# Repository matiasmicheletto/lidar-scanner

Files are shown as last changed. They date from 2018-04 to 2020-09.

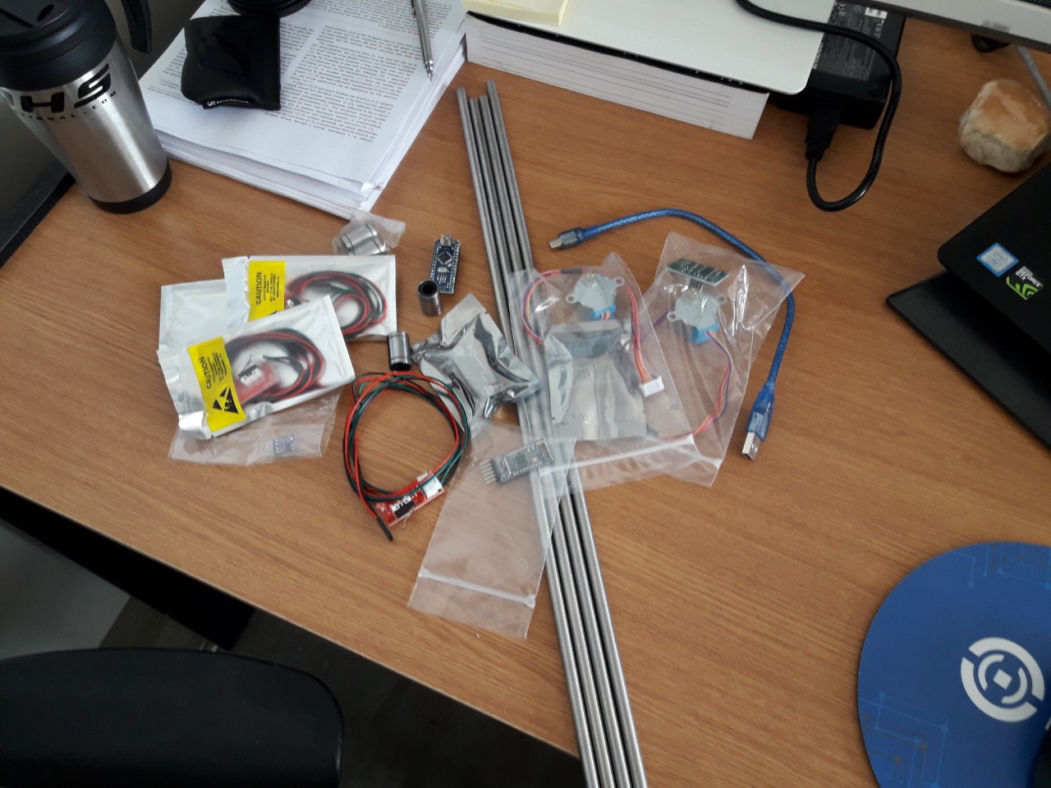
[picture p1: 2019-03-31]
Img/Materiales.jpeg

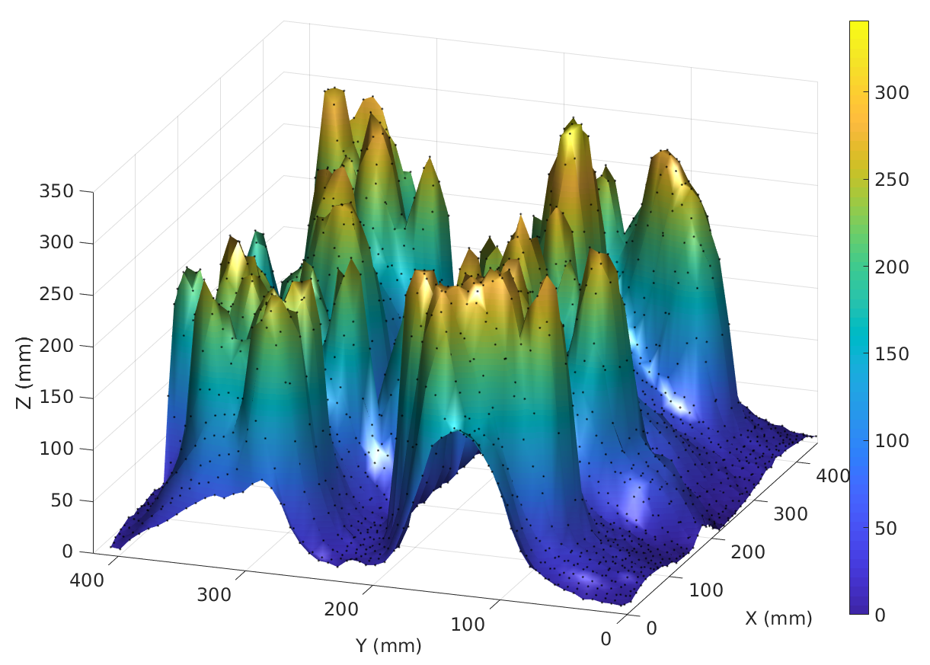
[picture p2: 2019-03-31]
Img/Modelo.png

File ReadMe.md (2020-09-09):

# Escáner Lidar para Análisis Tridimensional de Cobertura Vegetal de Suelos

Demo funcionando (https://www.youtube.com/watch?v=0Rp_0J8g25A)

## Resumen
http://47jaiio.sadio.org.ar/sites/default/files/CAI-10.pdf
"La erosión hídrica y eólica del suelo sobre el que se realizan actividades de producción agrícola implica la pérdida de nutrientes y microorganismos importantes. La presencia de rastrojos o cultivos de cobertura reduce en gran medida la erosión eólica al frenar el viento sobre la superficie, reduce la erosión hídrica al impedir el escurrimiento de agua, evita la pérdida de humedad por evaporación al estar el suelo protegido de la radiación solar, y también se evita fenómenos como el 'planchado' o 'sellado' del suelo que impide la emergencia de los cultivos sembrados luego de lluvias intensas. La cobertura vegetal debe contar con ciertas características para optimizar la calidad del suelo, y entre éstas se puede mencionar su altura y densidad volumétrica por lo que contar con un instrumento para la medición de éstas variables resulta de interés. Se presenta en este trabajo un prototipo que permite escanear la superficie del suelo midiendo la altura de la cobertura vegetal mediante un sensor de distancia accionado mediante un mecanismo CNC. Se detalla el funcionamiento tanto del sistema mecánico como electrónico y del software implementado como así también los resultados de las pruebas experimentales."

Ing. Electr. Matías Micheletto | Dep. de Ing. Eléctrica y Computadoras, IIIE Universidad Nacional del Sur - CONICET

### Contacto
LSD | Laboratorio de Sistemas Digitales  
DIEC | Departamento de Ingeniería Eléctrica y Computadoras  
UNS | Universidad Nacional del Sur  
San Andrés 800, CP8000 Bahía Blanca  
Buenos Aires, Argentina  
Teléfono: +54 291 4595153/4  
Website: http://www.diec.uns.edu.ar/rts

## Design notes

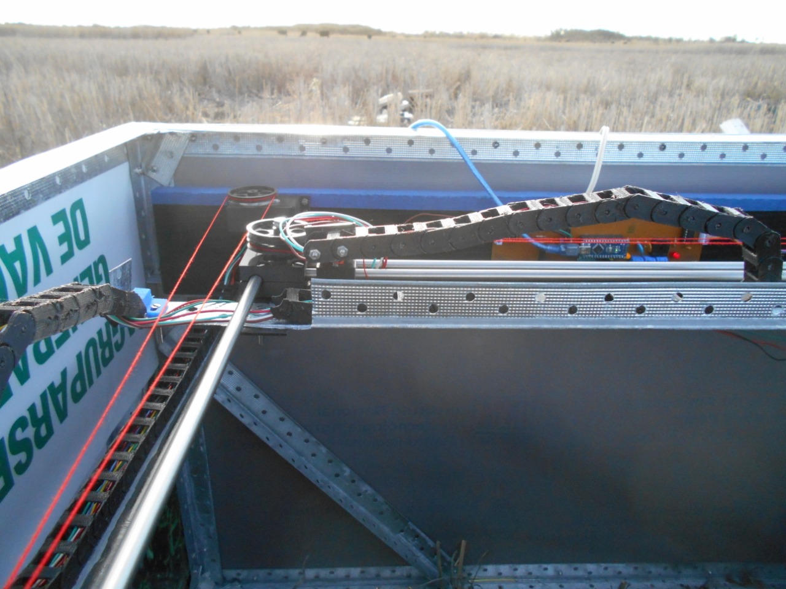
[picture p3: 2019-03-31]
Img/Campo3.jpeg

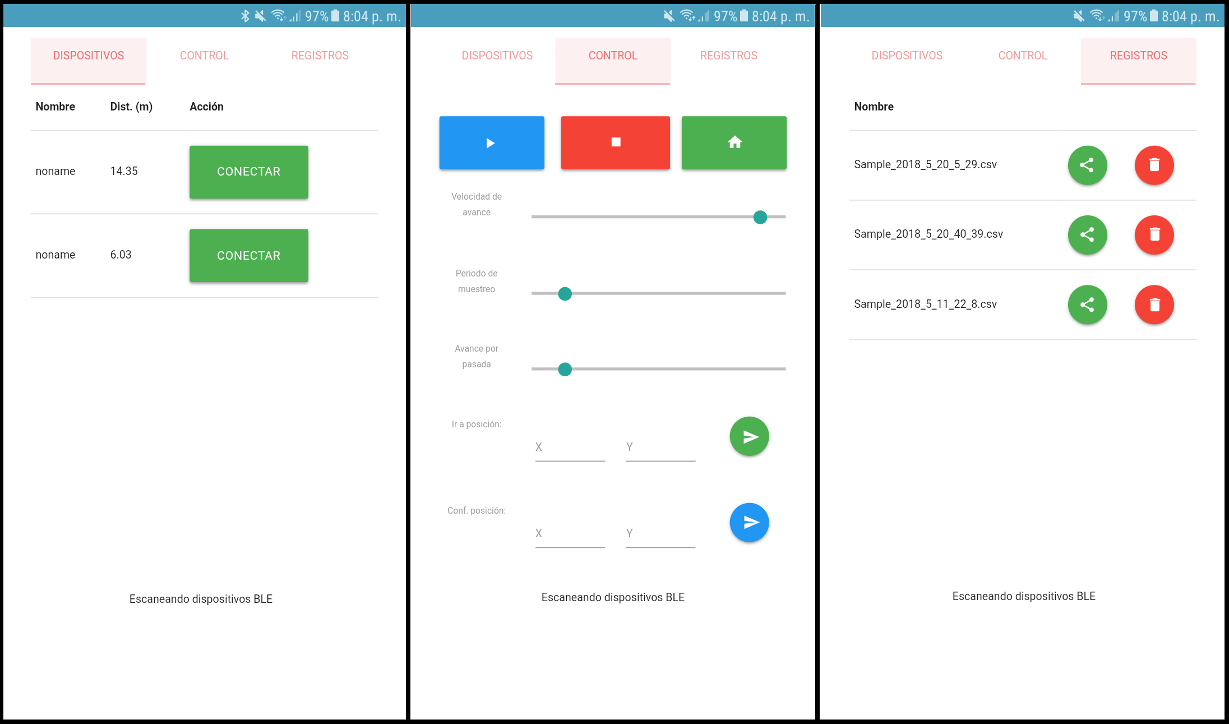
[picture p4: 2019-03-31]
Img/App.png

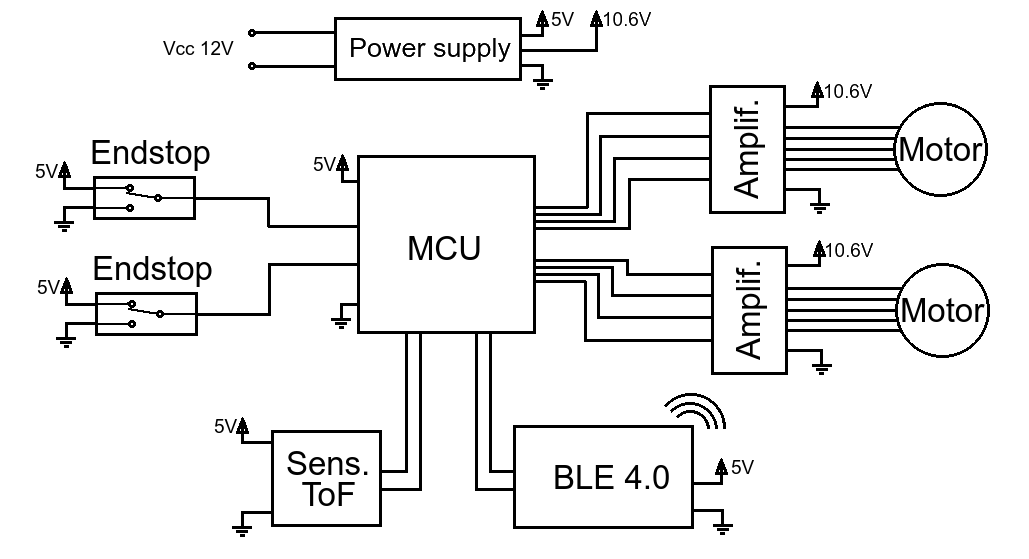
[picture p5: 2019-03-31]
Img/EsquemaGralElectrico.png

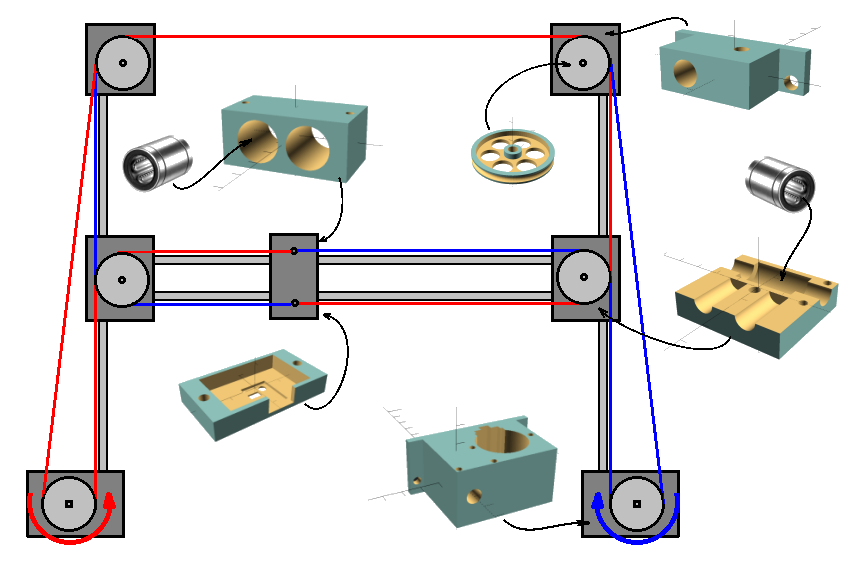
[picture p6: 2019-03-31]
Img/Mecanica13.png

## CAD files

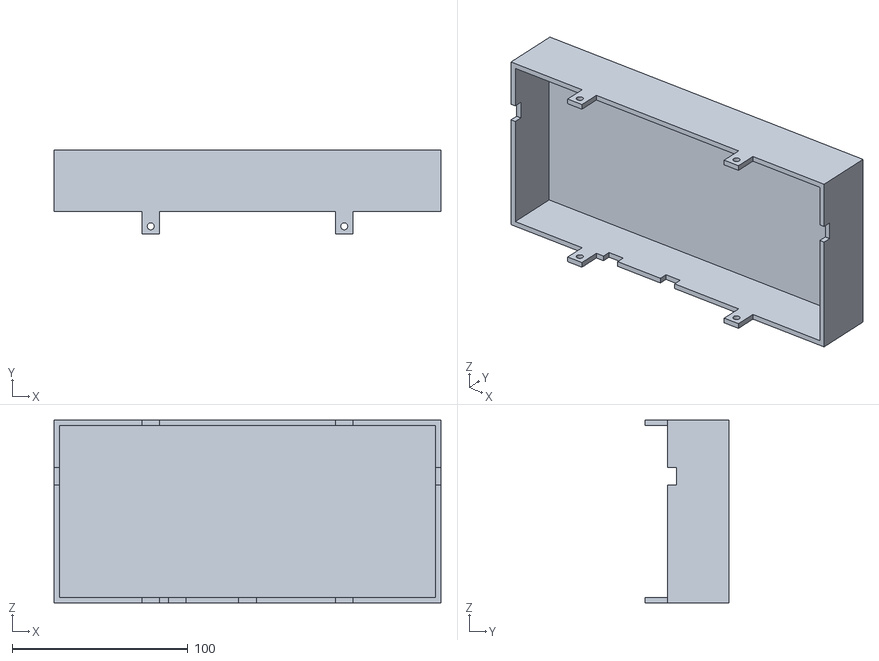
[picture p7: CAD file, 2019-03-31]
Partes/Gabinete.stl
220.0 x 48.0 x 104.0

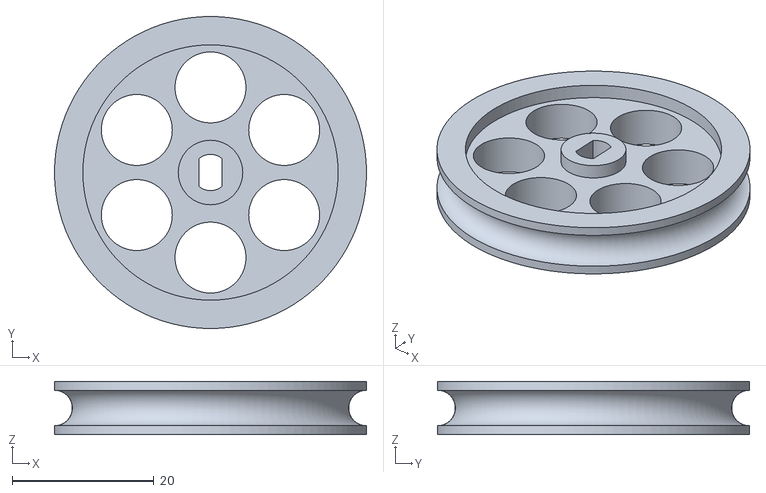
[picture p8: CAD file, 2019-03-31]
Partes/PoleaPistaAlta.stl
44.0 x 44.0 x 7.50

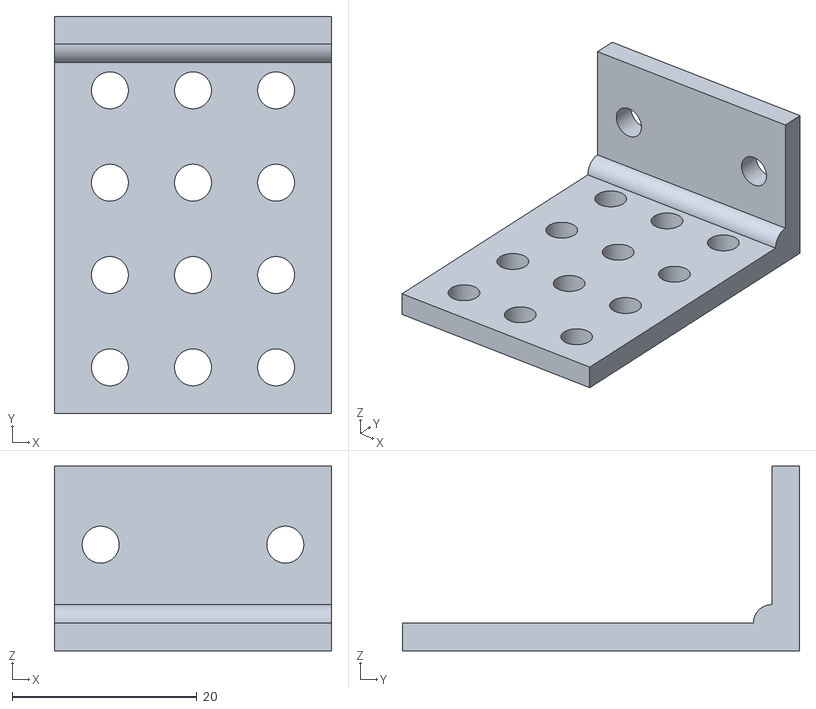
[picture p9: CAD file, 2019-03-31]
Partes/AnguloSoporteEstruc.stl
30.0 x 43.0 x 20.0

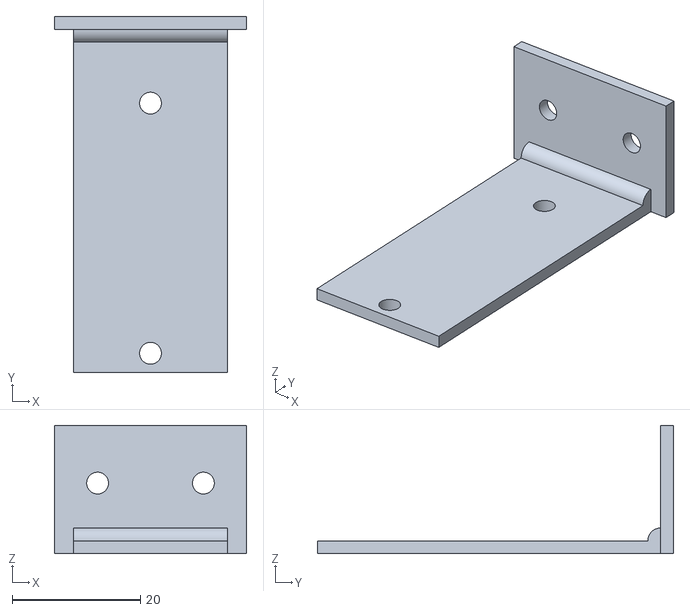
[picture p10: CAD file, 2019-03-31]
Partes/SoporteCadena.stl
30.0 x 55.5 x 20.0

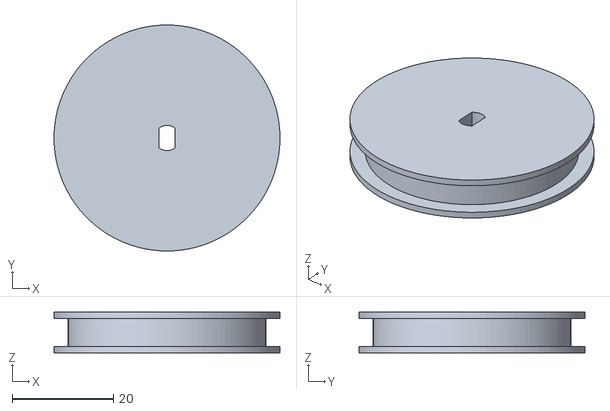
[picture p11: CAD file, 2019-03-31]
Partes/PoleaPistaRecta.stl
44.6 x 44.6 x 8.00

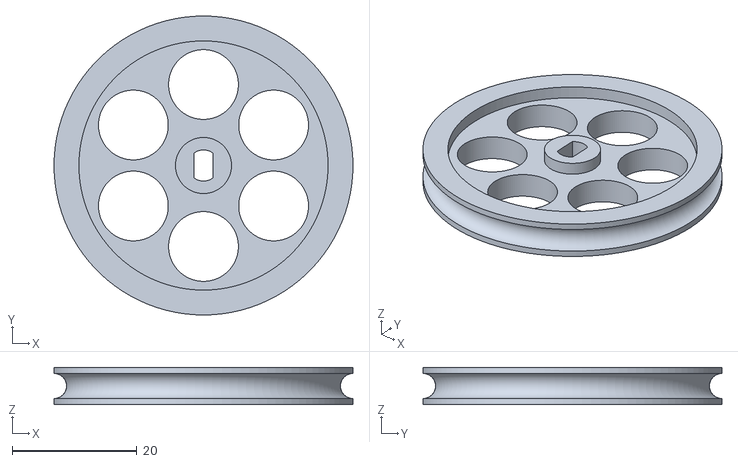
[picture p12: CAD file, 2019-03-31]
Partes/PoleaMotor.stl
48.0 x 48.0 x 6.00

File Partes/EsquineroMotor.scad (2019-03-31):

/*
    Scanner para análisis tridimensional de cobertura vegetal del suelo
    
    Descripción de la pieza: Soporte para las guias de desplazamiento Y y para los motores paso a paso. Posee espacio para ajustar los interruptores de fin de carrera.
    Cantidad requerida: 2.

    Autor: Matias J. Micheletto    
    Noviembre 2017
    Directores: Rodrigo Santos - Juan Galantini
    Laboratorio de Sistemas Digitales
    Universidad Nacional del Sur - Departamento de Ingeniería Eléctrica y Computadoras    
*/

$fn = 100;  // Resolucion del modelo

// Dimensiones exteriores del montaje
W = 57;     // Ancho (en direccion X)
L = 40;     // Largo (en direccion Y)
d = -19;      // Desplazamiento lateral

Ry = 4.1;   // Radio del orificio para eje y

ls = 4;     // Espesor de pared posterior
ds = 8;     // Ancho hacia los costados
Rs = 2.25;  // Radio de los agujeros para soportes

// Dimensiones del motor
dm = 39-12.25; // Separacion entre el eje Y y el eje del motor
Rm = 14+0.1; // Radio del motor
r2 = 1.7; // Radio de los agujeros para tornillos
d2 = 35; // Separacion entre los tornillos

// Espacio para soporte de cables
wc1 = 3+0.2; // Largo parte ancha
lc1 = 17+0.2; // Ancho parte ancha
xc1 = -dm+sqrt(Rm*Rm-lc1*lc1/4)+wc1/2; // Posicion del centro del cuadrado
wc2 = 5+0.2; // Largo parte angosta
lc2 = 14.5+0.2; // Ancho parte angosta
xc2 = -dm+sqrt(Rm*Rm-lc2*lc2/4)+wc2/2; // Posicion del centro del cuadrado
wc3 = 7; // Largo parte angosta
lc3 = 6; // Ancho parte angosta
xc3 = -dm+sqrt(Rm*Rm-lc3*lc3/4)+wc3/2; // Posicion del centro del cuadrado

// Ajuste del endstop
d3 = 19; // Separacion entre los tornillos

module pieza(H){ // Se pasa como argumento la altura de la pieza para dibujar una de las mitades mas alta
    difference(){ 
        // Envolvente        
        union(){
            translate([d,0,0])
                cube([W,L,H],center = true);
            translate([d,L/2-ls/2+ls,0])
                cube([W+2*ds,ls,H], center = true);
        }
            
        // Espacio para la guia de acero
        translate([0,-L/2+21/2,0])
        rotate([90,0,0])              
            cylinder(r = Ry, h = 21, center = true);                
           
        // Hueco para el motor
        translate([-dm,0,0])
            cylinder(r = Rm, h = H, center = true);
           
        // Orificios para los tornillos del motor        
        translate([-dm-d2/2,0,0])
            cylinder(r = r2, h = H, center = true);    
        translate([-dm+d2/2,0,0])
            cylinder(r = r2, h = H, center = true);
        
        // Espacio para los conectores del motor
        translate([-dm,xc1+dm,0])
            cube([lc1,wc1,H], center = true);
        translate([-dm,xc2+dm,0])
            cube([lc2,wc2,H], center = true);
        translate([-dm,xc3+dm,0])
            cube([lc3,wc3,H], center = true);    
        
        // Agujeros de soporte
        translate([W/2+ds/2+d,L/2+ls/2,-H/4])
        rotate([90,0,0])
            cylinder(r = Rs, h = ls, center = true);
        translate([-W/2-ds/2+d,L/2+ls/2,-H/4])
        rotate([90,0,0])
            cylinder(r = Rs, h = ls, center = true);  
        /*translate([W/2+ds/2+d,L/2+ls/2,H/4])
        rotate([90,0,0])
            cylinder(r = Rs, h = ls, center = true);
        translate([-W/2-ds/2+d,L/2+ls/2,H/4])
        rotate([90,0,0])
            cylinder(r = Rs, h = ls, center = true);*/
        
        
        // Agujeros para tornillos del endstop    
        translate([W/2-r2+d-0.5,-L/2+r2+0.5,0])   
            cylinder(r = r2, h = H, center = true);
        translate([W/2-r2+d-0.5-d3,-L/2+r2+0.5,0])   
            cylinder(r = r2, h = H, center = true);                
        
        // Dibujar solo la mitad de abajo
        translate([d,ls/2,H/4])
            cube([W+2*ds,L+ls,H/2], center = true);              
    }
}

pieza(32);
mirror([0,1,0]) // Reflejar respecto del plano XZ
translate([0,L+2,-6])
    pieza(20); // Uno de los motores debe ir mas alto que el otro

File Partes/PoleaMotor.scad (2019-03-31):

/*
    Scanner para análisis tridimensional de cobertura vegetal del suelo
    
    Descripción de la pieza: Polea de 40mm de diametro para motor paso a paso BYj48.
    Cantidad requerida: 2.

    Autor: Matias J. Micheletto    
    Noviembre 2017
    Directores: Rodrigo Santos - Juan Galantini
    Laboratorio de Sistemas Digitales
    Universidad Nacional del Sur - Departamento de Ingeniería Eléctrica y Computadoras    
*/

$fn = 100;      // Resolucion del modelo

H = 6;        // Altura
Rp = 2;       // Radio de la pista (menor que H/2)
R = 22+Rp;    // Radio exterior (original 19.5+Rp)

Ra = 2.50;      // Radio eje
Rb = 1.55;      // Achatamiento

// Orificios
Nh = 6;         // Cantidad
Rh = 5.6;         // Radio (original 5)
Dh = R/2+1;     // Separacion desde el centro

// Ahuecamiento
Di = 2;         // Borde interior
De = 4;         // Borde exterior
e = 2;          // Profundidad

    
    

difference(){
    cylinder(r = R, h = H); // Envolvente

    intersection(){
        cylinder(r = Ra, h = H); // Eje
        translate([0,0,H/2])
            cube([Rb*2,Ra*2,H], center = true);
    }

    // Pista para la cuerda convexa
    rotate_extrude(convexity = 10)
    translate([R, H/2, 0])
        circle(r = Rp);  
    
    // Pista para cuerda recta
    //translate([0,0,(H-Rp*2)/2])
    //difference(){
    //    cylinder(r = R, h = Rp*2);
    //    cylinder(r = R-Rp, h = Rp*2);
    //}
    

    // Orificios
    for(angle = [0 : 360/Nh : 360])
        translate([Dh*sin(angle),Dh*cos(angle),0])
            cylinder(r = Rh, h = H); 

    // Ahuecamiento superior
    translate([0,0,H-e])
        difference(){
            cylinder(r = R-De, h = e);
            cylinder(r = Ra+Di, h = e);
        }
}

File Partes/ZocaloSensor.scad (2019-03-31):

/*
    Scanner para análisis tridimensional de cobertura vegetal del suelo
    
    Descripción de la pieza: Zócalo para sensor laser VL53L0X. Va atornillado a la base del carro móvil que se desplaza sobre el eje X.
    Cantidad requerida: 1.

    Autor: Matias J. Micheletto    
    Noviembre 2017
    Directores: Rodrigo Santos - Juan Galantini
    Laboratorio de Sistemas Digitales
    Universidad Nacional del Sur - Departamento de Ingeniería Eléctrica y Computadoras    
*/

$fn = 100; // Resolucion del modelo

// Dimensiones exteriores del montaje
W = 24; // Ancho (en direccion X)
L = 45; // Largo (en direccion Y)
H = 7.5;  // Altura (en direccion Z)
e = 1.6;  // Espesor fondo y paredes

// Dimensiones del sensor
Ws = 2.4+0.2; // Ancho (X)
Ls = 4.4+0.2; // Alto (Y)

// Dimensiones y posicion de la plaqueta
Wp = 13.3+0.2; // Ancho (X)
Lp = 10.4+0.2; // Largo (Y)
ep = 1; // Espesor del hundimiento
xp = -2.2;
yp = -2.3;

// Dimensiones y posicion del tornillo de la plaqueta
Rs = 1.3+0.2; // Radio del orificio para el tornillo de la plaqueta
xs = 1.9;
ys = -4.7;

// Tornillos de ajuste
Rp = 1.8; // Radio de los orificios para tornillos
s = 1.5; // Separacion entre el orificio y el borde de la pieza



difference(){
    // Envolvente
    cube([W,L,H], center = true);
    
    // Interior
    translate([0,0,e/2])
        cube([W-2*e,L-4*s-4*Rp,H-e], center = true);
    
    // Agujeros para tornillos
    translate([0,L/2-Rp-s,0])
        cylinder(r = Rp, h = H, center = true);
    translate([0,-L/2+Rp+s,0])
        cylinder(r = Rp, h = H, center = true);
    
    // Orificio para sensor (centrado)
    translate([0,0,-H/2+e/2])
        cube([Ws,Ls,e], center = true);
    
    // Orificio para tornillo de la plaqueta
    translate([xs,ys,-H/2+e/2])
        cylinder(r = Rs, h = e, center = true);
    
    // Hueco para plaqueta    
    translate([xp,yp,-H/2+e-ep/2])
        cube([Wp,Lp,ep], center = true);
        
    // Agujero para sacar los cables
    translate([-W/2+e/2,yp,e/2])
        cube([e,Lp,H-e], center = true);
}

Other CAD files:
Partes/AnguloSoporteEstruc.scad
Partes/CadenaArrastre.scad
Partes/Carro.scad
Partes/Esquinero.scad
Partes/Gabinete.scad
Partes/MontajeCarro.scad
Partes/Polea.scad
Partes/SoporteCadena.scad
Partes/TopeEndstop.scad

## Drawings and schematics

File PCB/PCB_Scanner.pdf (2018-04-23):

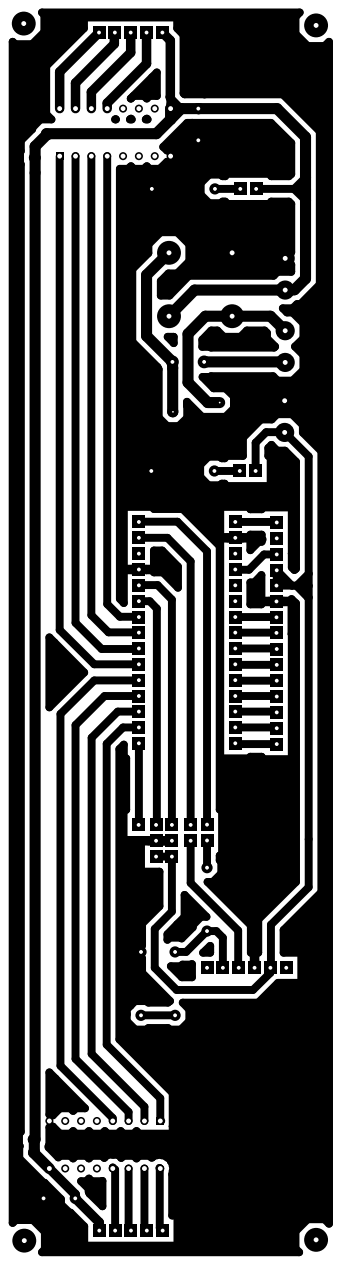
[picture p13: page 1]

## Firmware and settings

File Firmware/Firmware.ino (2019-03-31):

/**
  ******************************************************************************
  *  Name        : Firmware.ino
  *  Author      : Matias Micheletto
  *  Version     : 1.0
  *  Copyright   : GPLv3
  *  Description : Firmware de scanner lidar de cobertura vegetal
  ******************************************************************************
  *
  *  Copyright (c) 2018
  *  Matias Micheletto <matias.micheletto@uns.edu.ar>
  *  Departamento de Ingeniería Eléctrica - Universidad Nacional del Sur
  *  Laboratorio de Sistemas Digitales
  *
  *
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
  ******************************************************************************
  */

#include <Wire.h>
#include "BYJ48.h"
#include "VL53L0X.h"

#define ES_PIN1 2 // Pin para endstop de direccion X
#define ES_PIN2 3 // Pin para endstop de direccion Y
//#define OK_PIN A0 // Pin para led de encendido
//#define ERR_PIN A1 // Pin para led de errores
//#define MAXPOSX 14600 // Maxima posicion a desplazarse en X (446mm)
//#define MAXPOSY 13300 // Maxima posicion a desplazarse en Y (410mm)
#define MAXPOSX 13000 // Maxima posicion a desplazarse en X (446mm)
#define MAXPOSY 11700 // Maxima posicion a desplazarse en Y (410mm)

// Sensor laser
VL53L0X sensor;

// Motores
BYJ48 motor1(4,5,6,7); // Motor izq.
BYJ48 motor2(8,9,10,11); // Motor der.

boolean scanning = false; // Habilita o deshabilita el muestreo del sensor
boolean moving = false; // Habilita las instrucciones de la ISR del TIMER2 (Para accionar motores)
int pos[2] = {MAXPOSX,MAXPOSY}; // Posicion inicial del sensor (se asume)
int sp[2] = {0,0}; // Setpoint (inicialmente debe ester en 0,0)
int hSweep = 300; // Pasos de separacion entre cada pasada horizontal (divisor de MAXPOSY)
byte motorSpeed = 12; // Valor defeecto del registro de comparacion para ISR valor = 16MHz/1024/freq 
int samplePeriod = 250; // Periodo de muestreo del sensor
unsigned long previousMillis = 0;

void setup(){

  // Inicializar sensor laser
  Wire.begin();
  sensor.init();
  sensor.setTimeout(500); // Maximo periodo de espera
  sensor.setMeasurementTimingBudget(200000); // Modo high accuracy

  pinMode(ES_PIN1,INPUT);
  pinMode(ES_PIN2,INPUT);
  //pinMode(OK_PIN,OUTPUT);
  //pinMode(ERR_PIN,OUTPUT);

  Serial.begin(9600); // Inicializar interface uart (para bluetooth o usb)
  delay(500);

  goHome(); // Se ingresa como setpoint el origen (0,0)

  // Para que no se mueva en el inicio. Si se desea volver al home se puede con el comando correspondiente
  pos[0] = 0;
  pos[1] = 0;

  // Configurar registros de interrupcion
  configureSpeed(motorSpeed);

  // Encender led de status
  //digitalWrite(OK_PIN,HIGH);

  
  /*
  // Configuracion del modulo
  delay(1000);
  Serial.println("AT");
  delay(500);
  Serial.println("AT+ROLE0"); // Slave
  delay(500);
  Serial.println("AT+UUID0xFFE0"); // UUID
  delay(500);
  Serial.println("AT+CHAR0xFFE1"); // Characteristic
  delay(500);
  Serial.println("AT+NAMEScanner"); // Name
  delay(500);
  */
}

void es1_activated(){ // Interrupcion por activacion del endstop de direccion X
  pos[0] = 0; // Restablecer posicion horizontal
}

void es2_activated(){ // Interrupcion por activacion del endstop de direccion Y
  pos[1] = 0; // Restablecer posicion vertical
}

ISR(TIMER2_COMPA_vect){ // Interrupcion por timer 2 - Control de motores
  if(moving){ // Para deshabilitar el uso de la cola de setpoint en interrupciones
    if(pos[0] == sp[0] && pos[1] == sp[1]){ // Si se alcanza el setpoint
      if(scanning && pos[0] < MAXPOSX){ // Si hay otro setpoint al que ir
        // Poner siguiente sp
        if(pos[1] == MAXPOSY){          
          sp[0] = pos[0]+hSweep;
          sp[1] = 0;
        }else{
          sp[0] = pos[0]+hSweep;
          sp[1] = MAXPOSY;
        }
      }else{ // Si no hay mas setpoints, apagar steppers y salir
        motor1.disable();
        motor2.disable();
	      moving = false; // Deshabilitar el cuerpo de la ISR para no usar cola
        scanning = false; // Deshabilitar el envio de datos
        return;
      }
    }
    if(pos[0] < sp[0]){ // Mover izquierda
      motor1.stepCCW();
      motor2.stepCCW();
      pos[0]++;
      return;
    }
    if(pos[0] > sp[0]){ // Mover derecha
      motor1.stepCW();
      motor2.stepCW();
      pos[0]--;
      return;
    }
    if(pos[1] < sp[1]){ // Mover arriba
      motor1.stepCW();
      motor2.stepCCW();
      pos[1]++;
      return;
    }
    if(pos[1] > sp[1]){ // Mover abajo
      motor1.stepCCW();
      motor2.stepCW();
      pos[1]--;
      return;
    }
  }
}

void startScanning(){ // Crear cola de posiciones para barrido izq-der y abajo-arriba iniciando desde la pos. vert. actual
  scanning = false; // Deberia estar en false antes
  moving = false; // Deshabilitar cuerpo de ISR

  sp[0] = 0;
  sp[1] = MAXPOSY;

  // Al iniciar escaneo, deshabilitar interrupciones de sensores de fin de carrera por si se desconectan
  detachInterrupt(0);
  detachInterrupt(1);
  scanning = true;
  moving = true;
}

void allStop(){ // Detener y borrar cola de setpoints
  scanning = false; // Detener muestreo de distancia
  moving = false; // Para que no interrumpa durante la operacion sigte.
  motor1.disable();
  motor2.disable();
}

void goHome(){ // Volver al 0,0
  // Deshabilitar medicion de distancia y cuerpo de ISR
  scanning = false;
  moving = false;

  // Reiniciar la posicion por si hubo patinamiento
  pos[0] = MAXPOSX;
  pos[1] = MAXPOSY;

  // Verificar estado de los interruptores de fin de carrera (Tienen logica negativa)
  if(digitalRead( ES_PIN1 ) == LOW) pos[0] = 0;
  if(digitalRead( ES_PIN2 ) == LOW) pos[1] = 0;

  // Habilitar interrupciones para endstops
  attachInterrupt(0, es1_activated, FALLING); // Int. para pin 2
  attachInterrupt(1, es2_activated, FALLING); // Int. para pin 3

  sp[0] = 0; sp[1] = 0;

  moving = true; // Habilitar nuevamente el cuerpo de la ISR
}


void configureSpeed(byte timerCnt){ // Cambiar la velocidad de los motores
  moving = false; // Deshabilitar el cuerpo de la ISR (Aunque luego se deshabilita la ISR completa)
  motorSpeed = timerCnt; // Actualizar variable global
  noInterrupts();
  // Configuracion del TIMER 2
  TCCR2A = 0; // Normal operation
  TCCR2B = 0; // Normal operation
  TCNT2 = 0; // Inicializar en 0
  OCR2A = timerCnt; // Registro de comparacion = 16MHz/1024/freq
  TCCR2A |= (1 << WGM21); // Modo CTC
  TCCR2B |= (1 << CS20); // 1024 prescaler
  TCCR2B |= (1 << CS21); // 1024 prescaler
  TCCR2B |= (1 << CS22); // 1024 prescaler
  TIMSK2 |= (1 << OCIE2A); // Habilitar int.
  interrupts(); // Habilitar interrupciones nuevamente
  moving = true; // Habilitar ejecucion del cuerpo de la ISR
}

/*
void error(){ // Si algo sale mal, desactivar todo y encender led de error
  if(queue != 0)
    delete queue;
  noInterrupts();
  digitalWrite(OK_PIN,LOW);
  digitalWrite(ERR_PIN,HIGH);
  while(1); // Quedar aca hasta reiniciar
}
*/

void serialEvent(){ // Interrupcion de puerto serie

  String arg;
  switch((char) Serial.read()){
    
    // Orden directa
    case 'a': // Iniciar escaneo     
      startScanning();
      Serial.println("a"); // Ack
      break;
    case 'b': // Detener     
      allStop();
      Serial.println("b"); // Ack
      break;
    case 'c': // Volver a origen     
      goHome();
      Serial.println("c"); // Ack
      break;
    case 'n': // Setear home aqui (Igual que mandar m0,0)
      moving = false; // Deshabilitar ISR durante las sgtes instrucciones
      pos[0] = 0; pos[1] = 0; // Setear home
      sp[0] = 0; sp[1] = 0;
      moving = true; // La ISR lo vuelve a false 
      Serial.println("n");
      break;

    // Solicitudes
    case 'd': // Posiciones maximas
      Serial.print("d");
      Serial.print(MAXPOSX);
      Serial.print(",");
      Serial.println(MAXPOSY);
      break;
    case 'e': // Velocidad de los steppers
      Serial.print("e");
      Serial.println(motorSpeed);
      break;
    case 'f': // Periodo de muestreo del sensor
      Serial.print("f");
      Serial.println(samplePeriod);
      break;
    case 'g': // Avance vertical
      Serial.print("g");
      Serial.println(hSweep);
      break;
    case 'h': // Posicion actual
      Serial.print("h");
      Serial.print(pos[0]);
      Serial.print(",");
      Serial.print(pos[1]);
      Serial.print(",");      
      Serial.println(sensor.readRangeSingleMillimeters());
      break;    

    // Comandos con argumento
    case 'i': // Agregar setpoint a la cola
      arg = Serial.readStringUntil('\n'); // Leer argumento
      if( arg != "" ){ // Si el argumento no esta vacio
        int sep, x, y;
        sep = arg.indexOf(","); // Separador
        x = arg.substring(0,sep).toInt(); // Posicion X
        y = arg.substring(sep+1).toInt(); // Posicion Y
        // Limitar valores al rango de trabajo del escaner
        x = x < 0 ? 0 : x > MAXPOSX ? MAXPOSX : x;
        y = y < 0 ? 0 : y > MAXPOSY ? MAXPOSY : y;        
        sp[0] = x; sp[1] = y;   
        moving = true; // Habilitar movimiento de motores      
        Serial.println("i"); // Ack                
      }
      break;
    case 'j': // Cambiar velocidad de los steppers
      arg = Serial.readStringUntil('\n'); // Leer argumento
      configureSpeed( (byte) arg.toInt() ); // Pasar argumento
      Serial.println("j"); // Ack
      break;
    case 'k': // Cambiar periodo de muestreo del sensor
      arg = Serial.readStringUntil('\n'); // Leer argumento
      samplePeriod = arg.toInt();
      Serial.println("k"); // Ack
      break;
    case 'l': // Cambiar el avance vertical
      arg = Serial.readStringUntil('\n'); // Leer argumento
      hSweep = arg.toInt();
      Serial.println("l"); // Ack
      break;
    case 'm': // Setear posicion actual manualmente
      arg = Serial.readStringUntil('\n'); // Leer argumento
      if( arg != "" ){ // Si el argumento no esta vacio
        int sep, x, y;
        sep = arg.indexOf(","); // Separador
        x = arg.substring(0,sep).toInt(); // Posicion X
        y = arg.substring(sep+1).toInt(); // Posicion Y
        // Limitar valores al rango de trabajo del escaner
        pos[0] = x < 0 ? 0 : x > MAXPOSX ? MAXPOSX : x;
        pos[1] = y < 0 ? 0 : y > MAXPOSY ? MAXPOSY : y;        
        Serial.println("m"); // Ack        
      }
      break;
    default: 
      break;
   }
 }

 void loop(){
  if (millis() - previousMillis >= samplePeriod) {
    previousMillis = millis();    
    if(scanning){
      // Mostrar posision y lectura por serie
      //Serial.print("a"); // Prefijo del dato
      Serial.print(pos[0]);
      Serial.print(",");
      Serial.print(pos[1]);
      Serial.print(",");
      //  if (sensor.timeoutOccurred()) { Serial.println("ST"); }
      Serial.println(sensor.readRangeSingleMillimeters());
    }
  }
}

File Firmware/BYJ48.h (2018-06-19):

#ifndef BYJ48_h
#define BYJ48_h

#include <Arduino.h>

class BYJ48 {
public:
    BYJ48(int In1, int In2, int In3, int In4); // Constructor donde se indican los pines

    void enable();                             // Energizar (frenar)
    void disable();                            // Desenergizar
    void stepCW();                             // Avanzar un step
    void stepCCW();                            // Retroceder un step

private:
    void writeStep();                          // Actualizar salida
    int outputPins[4];                         // Numeros de los pines
    int currentStep;                           // Paso actual
    static const boolean sequences[8][4];      // Secuencias de pasos
};

// Secuencias
const boolean BYJ48::sequences[8][4] = {
                      // half-step 0-7
                      {false, false, false, true },
                      {false, false, true, true},
                      {false, false, true, false },
                      {false, true, true, false},
                      {false, true, false, false },
                      {true, true, false, false},
                      {true, false, false, false },
                      {true, false, false, true}
                    };

BYJ48::BYJ48(int In1, int In2, int In3, int In4){
    // Numero de pines de salida
    outputPins[0] = In1;
    outputPins[1] = In2;
    outputPins[2] = In3;
    outputPins[3] = In4;

    // Modo de pines de salida
    pinMode(outputPins[0], OUTPUT);
    pinMode(outputPins[1], OUTPUT);
    pinMode(outputPins[2], OUTPUT);
    pinMode(outputPins[3], OUTPUT);

    // Disponer salida en step inicial (HS)
    currentStep = 0;
    writeStep();
}

void BYJ48::enable(){
    // Alimentar bobinas para que quede frenado
    writeStep();  
}

void BYJ48::disable(){
    // Desalimentar todas para que quede liberado
    digitalWrite(outputPins[0], LOW);
    digitalWrite(outputPins[1], LOW);
    digitalWrite(outputPins[2], LOW);
    digitalWrite(outputPins[3], LOW);
}

void BYJ48::stepCW(){
    // Incrementar paso
    currentStep = currentStep >= 7 ? 0 : currentStep+1;
    writeStep();
}

void BYJ48::stepCCW(){
    // Decrementar paso
    currentStep = currentStep <= 0 ? 7 : currentStep-1;
    writeStep();
}

void BYJ48::writeStep(){
    digitalWrite(outputPins[0], sequences[currentStep][0]);
    digitalWrite(outputPins[1], sequences[currentStep][1]);
    digitalWrite(outputPins[2], sequences[currentStep][2]);
    digitalWrite(outputPins[3], sequences[currentStep][3]);
}


#endif //BYJ48

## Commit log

2017-10-19 Velocidad del motor senoidal
2017-10-19 Cambiado el periodo de la senoide
2017-10-24 Reorganizacion de los archivos
2017-10-24 Implementado medicion continua de distancia
2017-11-06 Testeos para el stepper BYJ48
2017-11-06 Modificaciones a la libreria del BYJ48
2017-11-07 Mejoras a la libreria BYJ48 - Pruebas de velocidad maxima
2017-12-14 Armado del firmware definitivo. Control de la posicion del sensor. TODO: Programar movimiento de zig-zag y empezar a trabajar con el sensor.
2017-12-18 Cambios en el algoritmo de control de motores
2017-12-20 Implementado el control de los motores y la adquisicion de datos desde el sensor. TODO: Control por Bluetooth.
2017-12-20 Implementado segundo ejemplo de Bluetooth que no utiliza SoftwareSerial
2018-02-20 Pruebas con firmware definitivo. Implementado los metodos home, stop y barrido en zig-zag. TODO: Enviar setpoints por serie y configurar el vSweep
2018-04-19 Algunos cambios en el firmware e implementación de un testeo distinto para el modulo BLE
2018-04-23 Limpieza del directorio. TODO: Implementar software para adquirir datos del scanner.
2018-06-05 Implementada la primera version de la app para controlar el escaner. TODO: Agregar control manual de posicion del sensor.
    [Ensayo_oficina_luz.csv, Ensayo_oficina_oscuro.csv, RegScanner.csv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]
2018-06-06 Modificado el protocolo de comunicacion para poder configurar variables
2018-06-19 Cambios en el firmware. Verificar funcionamiento de control por USB y luego desde la app.
    [Ensayo_oficina_luz.csv, Ensayo_oficina_oscuro.csv, RegScanner_1.csv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]
2018-10-25 Quite la lista enlazada para no llenar la memoria con setpoints en modelos de alta resolucion.
2019-03-31 Agregado carpeta de piezas
    [AnguloSoporteEstruc.scad, AnguloSoporteEstruc.stl, CadenaArrastre.scad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]
2020-09-09 Nuevo test steppers. Cambios libreria byj48
    [Esquinero.scad, MontajeCarro.scad, Polea.scad]
2020-09-09 Scripts para analizar datos
2020-09-13 Analisis de datos
2021-09-02 Analisis de submuestreo de modelos
    [high_res.csv]
2025-05-08 Agregado LICENSE
    Se incluye la licencia GNU General Public License para el uso del contenido del repositorio.

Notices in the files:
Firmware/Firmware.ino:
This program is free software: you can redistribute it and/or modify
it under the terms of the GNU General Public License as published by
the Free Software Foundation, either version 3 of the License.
